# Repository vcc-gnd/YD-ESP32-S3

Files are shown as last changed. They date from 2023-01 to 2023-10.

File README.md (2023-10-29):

# YD-ESP32-S3 Core Board 

###### 简介：

YD-ESP32-S3核心板由源地工作室（VCC-GND Studio）设计，有需要可以浏览www.vcc-gnd.com 获取购买。该设备使用ESP32-S3芯片，可以用于物联网应用的测试原型机也就可以用于实际应用，配有两个usb一个是硬件的usb转串口(CH343P WCH 沁恒)，一个是ESP32-S3的usb口。

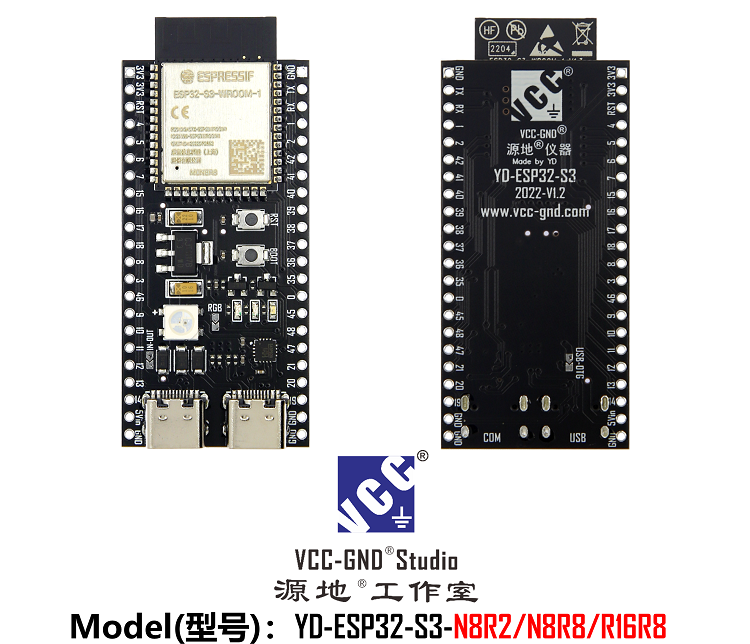
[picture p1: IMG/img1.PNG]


本指南将帮助您快速上手 YD-ESP32-S3，并提供该款开发板的详细信息。

YD-ESP32-S3 是一款入门级开发板，搭载 Wi-Fi + Bluetooth® LE 模组 ESP32-S3-WROOM-1。

板上模组的大部分管脚均已引出至开发板两侧排针，开发人员可根据实际需求，轻松通过跳线连接多种外围设备，也可将开发板插在面包板上使用。
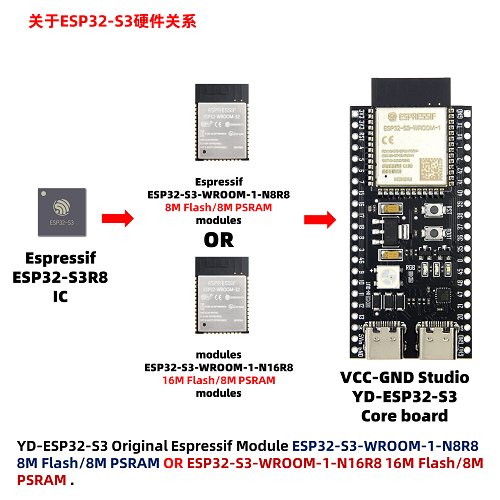
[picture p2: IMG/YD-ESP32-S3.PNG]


1、这就是一个ESP32-S3的最小核心板，使用时乐鑫公司的ESP32-S3模块。
2、无线功能专用的LDO电路，不用担心电流（功率）不够用的情况。
3、配有一颗WS2812-RGB LED(注意并不是通过GPIO直接点亮)。
4、RST按键用于外部复位功能，boot按键（配合rst按键可以引导进入bootloard 模式，在复位后可以当做用户按键，就是GPIO0）。
5、你会发现板子有两个TYPE-C接口（一个是直连usb（GPIO19 GPIO20）,另一个是USB转串口的usb口），配有硬件的usb转串口芯片（CH343）。

###### 硬件介绍：

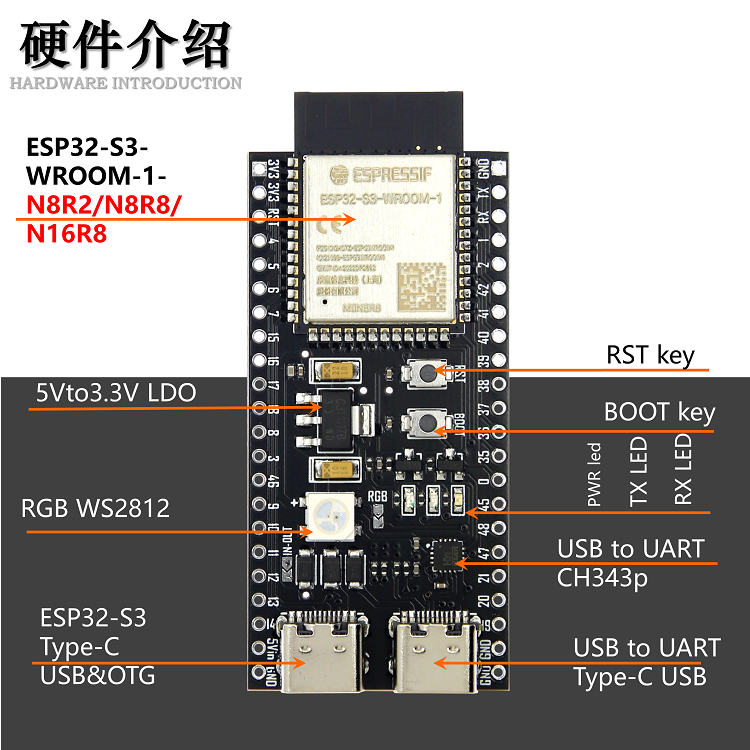
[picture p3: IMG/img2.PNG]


| 主要组件 | 介绍 |
| :--- | --- |
| ESP32-S3-WROOM-1 | ESP32-S3-WROOM-1 是通用型 Wi-Fi + 低功耗蓝牙 MCU 模组，具有丰富的外设接口、强大的神经网络运算能力和信号处理能力，专为人工智能和 AIoT 市场打造。ESP32-S3-WROOM-1  采用 PCB 板载天线。 |
| 5 V to 3.3 V LDO（5 V 转 3.3 V LDO） | 电源转换器，输入 5 V，输出 3.3 V,电流为1A |
| Pin Headers（排针） | 所有可用 GPIO 管脚（除 flash 的 SPI 总线）均已引出至开发板的排针。 |
| USB-to-UART Port（USB 转 UART 接口） | Type-c-USB 接口，可用作开发板的供电接口，可烧录固件至芯片，也可作为通信接口，通过板载 USB 转 UART 桥接器与芯片通信。 |
| Boot Button（Boot 键） | 下载按键。按住 **Boot** 键的同时按一下 **Reset** 键进入“固件下载”模式，通过串口下载固件。如果启动完毕可以当做普通的输入按键使用，使用到的IO为GPIO0。 |
| Reset Button（Reset 键） | 复位按键。 |
| USB Port（USB 接口） | ESP32-S3 USB OTG 接口，支持全速 USB 1.1 标准。ESP32-S3 USB 接口可用作开发板的供电接口，可烧录固件至芯片，可通过 USB 协议与芯片通信，也可用于 JTAG 调试。 |
| USB-to-UART Bridge（USB 转 UART 桥接器） | 芯片为CH343P,厂商为沁恒，网址为http://www.wch-ic.com/ 驱动：http://www.wch-ic.com/products/CH343.html? |
| RGB LED | 可寻址 RGB 发光二极管，由 GPIO48 驱动。型号为WS2812。 |
| PWR LED | 电源指示灯，板子供电后，亮起，不可以程序控制。 |
| TX LED | ESP32-S3的串口TXD线路上的led,当有串口数据发出时，LED闪烁，如果不使用串口功能可以当做GPIO使用,GPIO43 |
| RX LED | ESP32-S3的串口RXD线路上的led,当有串口数据接收时，LED闪烁，如果不使用串口功能可以当做GPIO使用，GPIO44 |

###### 备注:

在板载 ESP32-S3-WROOM-1 模组系列（使用 8 线 SPI flash/PSRAM）的开发板，管脚 GPIO35、GPIO36 和 GPIO37 已用于内部 ESP32-S3 芯片与 SPI flash/PSRAM 之间的通信，外部不可使用。

###### 开始开发应用:
通电前，请确保开发板完好无损。

###### 功能框图：
YD-ESP32-S3 的主要组件和连接方式如下图所示：

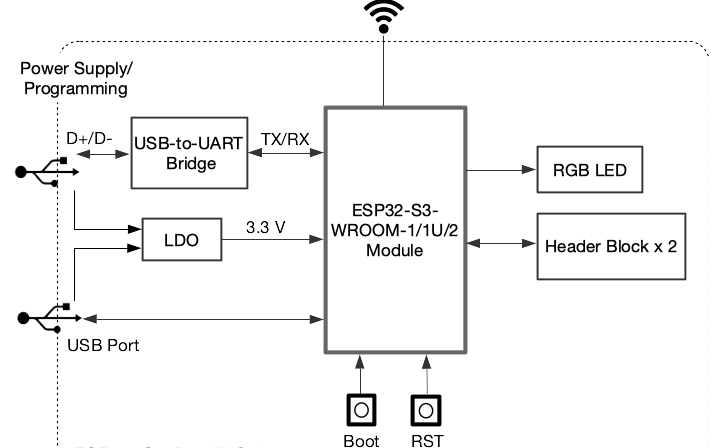
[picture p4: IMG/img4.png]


###### 电源选项:
您可从以下三种供电方式中任选其一给开发板供电：

USB 转 UART 接口供电或 ESP32-S3 USB 接口供电（选择其一或同时供电），默认供电方式（推荐）

5V 和 G (GND) 排针供电

3V3 和 G (GND) 排针供电

###### 排针:
下表列出了开发板两侧排针（P1 和 P2）的 名称 和 功能，排针的名称如图 YD-ESP32-S3正面 所示，排针的序号与 开发板原理图 (PDF) 一致。

###### P1

| 序号 | 名称 | 类型  | 功能 |
| ---- | ---- | ----- | --- |
| 1 | 3V3  | P | 3.3 V 电源 |
| 2 | 3V3  | P | 3.3 V 电源 |
| 3 | RST  | I | EN |
| 4 | 4 | I/O/T | RTC_GPIO4, GPIO4, TOUCH4, ADC1_CH3 |
| 5 | 5 | I/O/T | RTC_GPIO5, GPIO5, TOUCH5, ADC1_CH4 |
| 6 | 6 | I/O/T | RTC_GPIO6, GPIO6, TOUCH6, ADC1_CH5 |
| 7 | 7 | I/O/T | RTC_GPIO7, GPIO7, TOUCH7, ADC1_CH6 |
| 8 | 15 | I/O/T | RTC_GPIO15, GPIO15, U0RTS, ADC2_CH4, XTAL_32K_P |
| 9 | 16 | I/O/T | RTC_GPIO16, GPIO16, U0CTS, ADC2_CH5, XTAL_32K_N |
| 10 | 17 | I/O/T | RTC_GPIO17, GPIO17, U1TXD, ADC2_CH6 |
| 11 | 18 | I/O/T | RTC_GPIO18, GPIO18, U1RXD, ADC2_CH7, CLK_OUT3 |
| 12 | 8 | I/O/T | RTC_GPIO8, GPIO8, TOUCH8, ADC1_CH7, SUBSPICS1 |
| 13 | 3 | I/O/T | RTC_GPIO3, GPIO3, TOUCH3, ADC1_CH2 |
| 14 | 46 | I/O/T | GPIO46 |
| 15 | 9 | I/O/T | RTC_GPIO9, GPIO9, TOUCH9, ADC1_CH8, FSPIHD, SUBSPIHD |
| 16 | 10 | I/O/T | RTC_GPIO10, GPIO10, TOUCH10, ADC1_CH9, FSPICS0, FSPIIO4, SUBSPICS0 |
| 17 | 11 | I/O/T | RTC_GPIO11, GPIO11, TOUCH11, ADC2_CH0, FSPID, FSPIIO5, SUBSPID |
| 18 | 12 | I/O/T | RTC_GPIO12, GPIO12, TOUCH12, ADC2_CH1, FSPICLK, FSPIIO6, SUBSPICLK |
| 19 | 13 | I/O/T | RTC_GPIO13, GPIO13, TOUCH13, ADC2_CH2, FSPIQ, FSPIIO7, SUBSPIQ |
| 20 | 14 | I/O/T | RTC_GPIO14, GPIO14, TOUCH14, ADC2_CH3, FSPIWP, FSPIDQS, SUBSPIWP |
| 21 | 5V | P | 5 V 电源 |
| 22 | G | G | 接地 |

###### P2

| 序号 | 名称 | 类型  | 功能 |
| ---- | ---- | ----- | --- |
| 1 | G | G | 接地 |
| 2 | TX | I/O/T | U0TXD, GPIO43, CLK_OUT1 |
| 3 | RX | I/O/T | U0RXD, GPIO44, CLK_OUT2 |
| 4 | 1 | I/O/T | RTC_GPIO1, GPIO1, TOUCH1, ADC1_CH0 |
| 5 | 2 | I/O/T | RTC_GPIO2, GPIO2, TOUCH2, ADC1_CH1 |
| 6 | 42 | I/O/T | MTMS, GPIO42 |
| 7 | 41 | I/O/T | MTDI, GPIO41, CLK_OUT1 |
| 8 | 40 | I/O/T | MTDO, GPIO40, CLK_OUT2 |
| 9 | 39 | I/O/T | MTCK, GPIO39, CLK_OUT3, SUBSPICS1 |
| 10 | 38 | I/O/T | GPIO38, FSPIWP, SUBSPIWP |
| 11 | 37 | I/O/T | SPIDQS, GPIO37, FSPIQ, SUBSPIQ |
| 12 | 36 | I/O/T | SPIIO7, GPIO36, FSPICLK, SUBSPICLK |
| 13 | 35 | I/O/T | SPIIO6, GPIO35, FSPID, SUBSPID |
| 14 | 0 | I/O/T | RTC_GPIO0, GPIO0 |
| 15 | 45 | I/O/T | GPIO45 |
| 16 | 48 | I/O/T | GPIO48, SPICLK_N, SUBSPICLK_N_DIFF, RGB LED |
| 17 | 47 | I/O/T | GPIO47, SPICLK_P, SUBSPICLK_P_DIFF |
| 18 | 21 | I/O/T | RTC_GPIO21, GPIO21 |
| 19 | 20 | I/O/T | RTC_GPIO20, GPIO20, U1CTS, ADC2_CH9, CLK_OUT1, USB_D+ |
| 20 | 19 | I/O/T | RTC_GPIO19, GPIO19, U1RTS, ADC2_CH8, CLK_OUT2, USB_D- |
| 21 | G | G | 接地 |
| 22 | G | G | 接地 |

P：电源；I：输入；O：输出；T：可设置为高阻。

###### 引脚图：

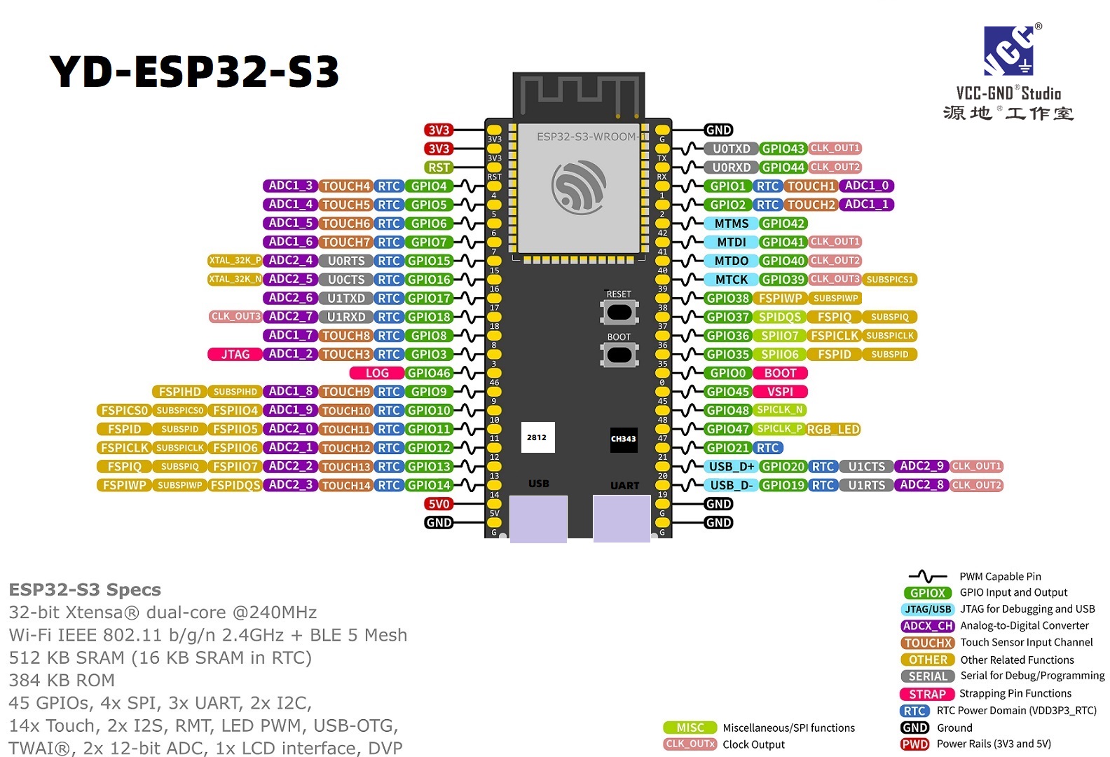
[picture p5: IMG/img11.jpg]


###### CH340芯片的驱动官方链接：

http://www.wch-ic.com/products/CH340.html?        ENGLISH

https://www.wch.cn/products/CH340.html?from=list     中文

Micropython固件下载：

ESP32-S3的下载擦除工具软件flash_download_tool_3.9.2_0在win下downloard tool。
注意：无需安装解压既用，双击小齿轮标志，选择ESP32-S3，develop，USART，剩下看图片，注意起始地址为0x00，前面打对号。如果不能下载可能是USB转串口驱动没有安好，先处理好驱动问题再来下载。

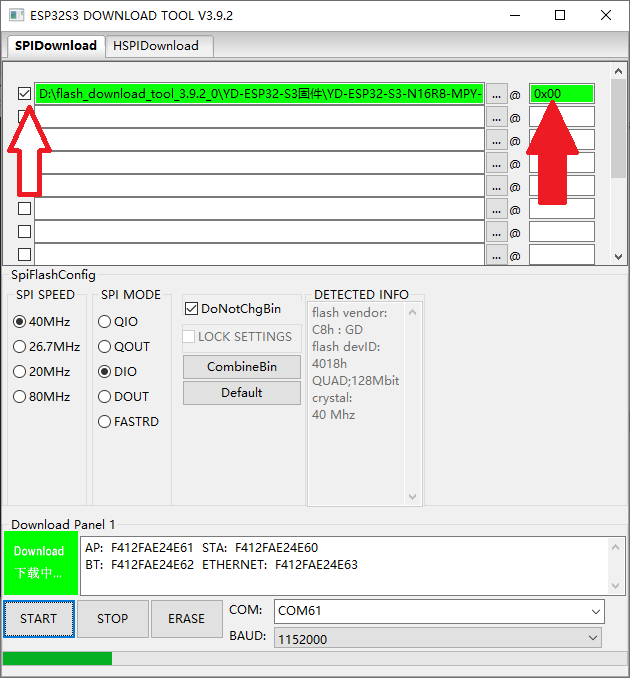
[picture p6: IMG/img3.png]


注意：

不能用thonny自带的所谓的ESP32下载器给ESP32-S3下载micropython固件(thonny自带的是给esp32下载的，型号并不是esp32-s3  地址也并不是S3的0x00而是ESP32的0x1000)，也不能使用micropython官方下载的带SPRAM固件，下载后也不能正常使用，正确的下载方式是使用乐鑫官方的flash tool下载工具，选择ESP32-S3 串口下载（USART）插入板子的COM端口的usb，选择对应的固件（我们源地自己改编的固件）起始地址是0x00 固件选择前打对号，最好先擦除再下载。
固件是1-开头链接的和固件下载软件是2-开头的链接，注意使用前最好更新一下CH343usb转串口的硬件驱动，注意事项在0-开头的资料链接中，在设备管理器中确认出现有……CH343字样COM才行。

如果下载TASMOTA固件，TASMOTA官方有自己的web下载。

https://tasmota.github.io/docs/

如果你下载自己的固件文件可以使用乐鑫的下载工具。

https://www.espressif.com.cn/en/home

这段文字是ESP32-S3的资料。 基础资料包括（硬件串口CH343驱动，源地版本micropython固件，下载固件的软件、micropython的IDE、原理图尺寸图等）：http://124.222.62.86/yd-data/YD-ESP32-S3/ 

如果计划使用官方的idf-C语言编程详细资料链接（例程就是的API参考）： https://docs.espressif.com/projects/esp-idf/zh_CN/latest/esp32s3/get-started/index.html 

如果计划使用Ardiuno编程资料链接： https://docs.espressif.com/projects/arduino-esp32/en/latest/getting_started.html#about-arduino-esp32 

如果计划使用micropython语言编程资料链接如下（注意快速入门看ESP32就行）： https://docs.micropython.org/en/latest/esp32/quickref.html
###### 山寨/假冒/劣质仿造的问题：

寨/假冒/劣质仿造我们源地（YD）开发板有很多，以深圳华强北最为猖獗，山寨者惯用的形式为直接打磨我们的开发板进行拍照抄板，以致山寨的产品隐患重重。现总结购买山寨板的危害（隐患）。
以YD-ESP32（ESP32/S2/S3/C3）系列为例：

1、山寨厂家为进一步追求利润，往往使用翻新，非官方器件，任意替换为同封装的廉价型号，乱选型，图利润

2、2812灯不焊接信号，无法使用2812，从侧面印证抄袭者不检查板子，图省事，压成本

3、山寨板出厂不检查（压缩成本），下完生产线就包装，发给消费者，省环节，图利润

4、山寨板由于照片抄袭，多处丝印抄错，容易误导消费者，抄袭者自己都搞不明白

5、山寨板抄袭是1.2版本是2022年早期版本，正版是1.4版本，山寨无法使用更新的功能，图省事不改进

6、山寨板使用的是第三方“山寨”模组（成本低），山寨模组没有经过阻抗匹配，在使用WIFI 蓝牙时候，功耗高信号差、易死机

7、山寨板由于在市面上找不到我们用专用LDO，就任意选择不合适型号，例如1117（成本低），压差大，易死机，信号差

8、山寨板使用高压差的二极管（大于0.7V管压降，成本低），造成后端LDO压差不足，进一步造成功耗高，易死机，信号差

9、山寨板不提供基本技术，就连资料都是直接复制我们的（资料还是我们早期的，最新资料山寨者都懒得找），钱收后，就不管了

10、山寨板启动有时候有问题，直接进入BootLoader，造成无法使用，山寨者都不明白这是什么问题！

11、山寨板仿冒者由于是照片抄板，所以没有原理图，让用户搞不懂如何使用，山寨者也不懂，造成产品难以使用。

有山寨者直接在山寨板子上印有YD-ESP32等字样以此来混淆视听，更有甚者，将我们官方网址WWW.VCC-GND.COM印在山寨仿冒品上，该行为已经触发相关法律，我们定会追究，请广大消费者不要贪图几毛钱~几块的一时便宜而承担以上种种风险，白白浪费时间和精力，支持源地支持正品，购买请认准源地，VCC-GND商标。

###### 通过内部交换矩阵可以实现引脚上的任意功能：

在各种ESP32系列文档介绍中注明了具备各种外设通讯功能例如I2C、I2S、UART、SPI等。但是又在功能引脚上示意图没有标注这些功能是哪个引脚。这个疑问在外设管脚分配中得到了解答，诸如I2C、I2S、UART、SPI等外设接口可以被定义为任意GPIO管脚，所以就没有必要在 功能示意图上标注出来了，反正任何一个GPIO都可以赋予这些外设接口I2C、I2S、UART、SPI功能所需要的引脚某个引脚功能。

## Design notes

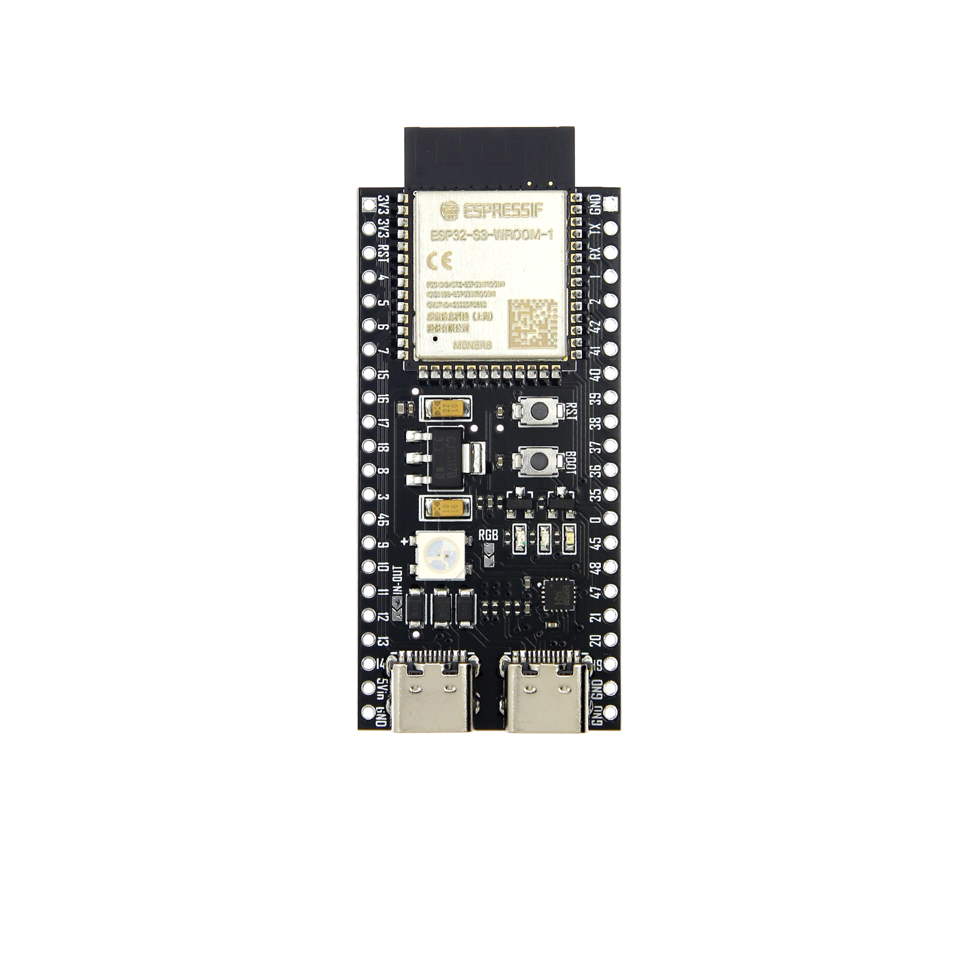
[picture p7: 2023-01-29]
5-public-YD-ESP32-S3-Hardware info/YD-ESP32-S3.PNG

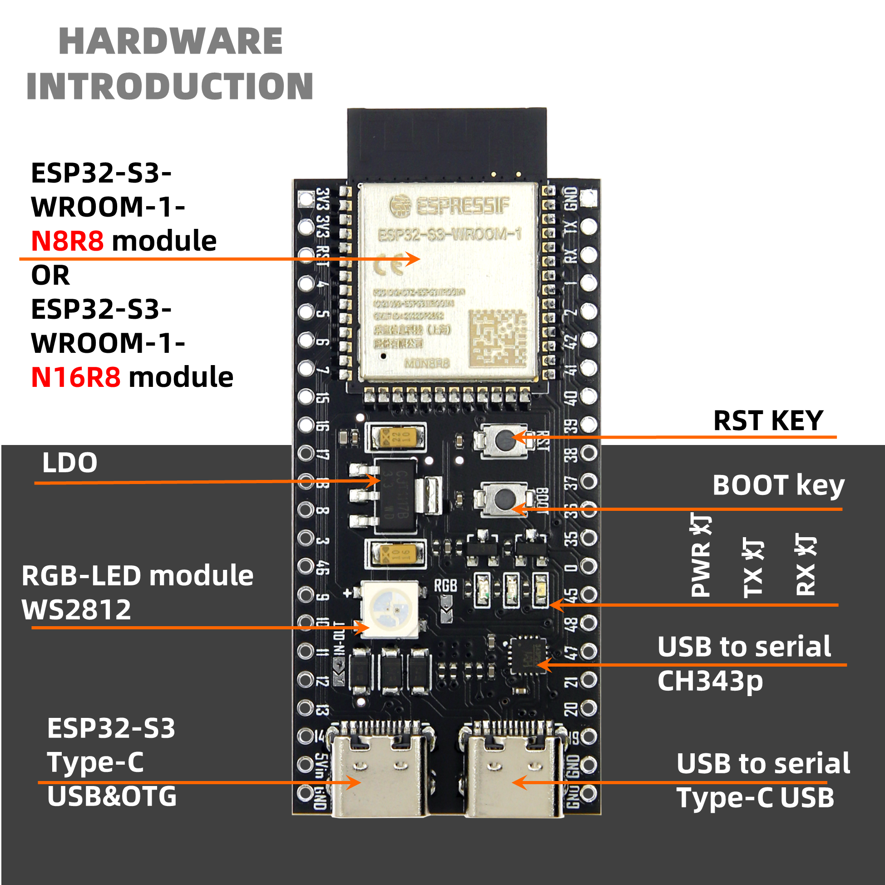
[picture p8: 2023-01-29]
5-public-YD-ESP32-S3-Hardware info/S3-V1.2 (14).PNG

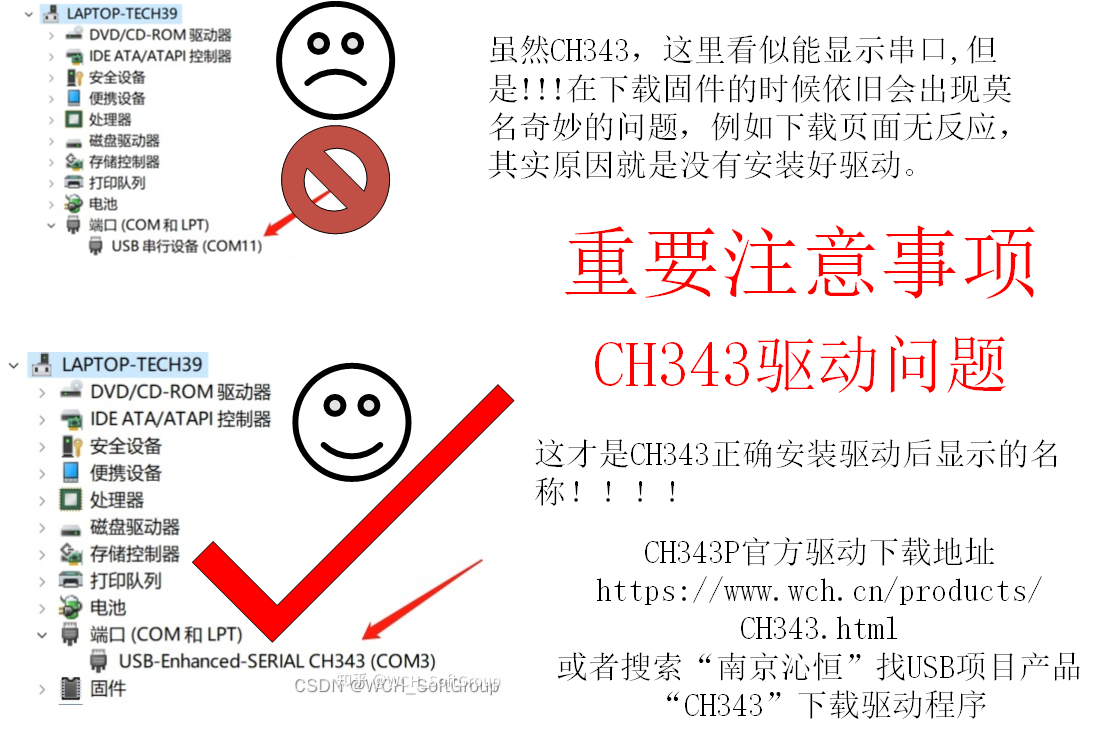
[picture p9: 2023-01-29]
0-public-USB to serial CH343 driver(important)/0-CH343驱动说明.png

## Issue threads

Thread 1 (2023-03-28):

RGB LED on PIN 48 not working?

PBrunot, 2023-03-28:
I am unable to get the RGB LED to work on  YD-ESP32-S3 N8R2 2022-V1.3 with standard Micropython and recent Micropython with NeoPixel library. Oscilloscope attached to GPIO48 shows no 800 KHz output.

Another user has the same issue, with board V1.4.

Is this a known problem ? Any workaround ?

See for more details : https://github.com/orgs/micropython/discussions/11097

PBrunot, 2023-03-29:
I think I have a defective ESP32 because the GPIO 48 is not outputting any signal, and if I connect NeoPixel on board to GPIO 10, it works fine.

mikadoryu, 2023-03-30:
First of all, do I solder the rgb pads that connect it to pin 48? I had the same problem that the rgb led did not work until I had to activate the led.
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

tyg6, 2023-06-24:
@mikadoryu @PBrunot I had the same problem, could you please explain more simply how to activate the led? Many thanks!
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

PBrunot, 2023-06-24:
@tyg6  : you just need to add a bit of solder on the jumper below the RGB letters with your soldering pan, so that the circuit to the NeoPixel is closed. From your photo there is a gap between the two jumpers pins, so the NeoPixel will not work without this addition.

tyg6, 2023-06-24:
@PBrunot Thanks for your quick reply! Got your point!

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

tyg6, 2023-06-24:
It works! finally I found the gap should be a 0603 10kΩ resistor.
It's a good design, cause you can use the GPIO 48 for other functions.
But it is frustrating there is no document for this tip.

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

vcc-gnd, 2023-09-07:
你购买是板子是山寨板，需要短接

At 2023-06-25 03:28:19, "Shuhu Liu" ***@***.***> wrote:

It works! finally I found the gap should be a 0603 10kΩ resistor.
It's a good design, cause you can use the GPIO 48 for other functions.
But it is frustrating there is no document for this tip.

—
Reply to this email directly, view it on GitHub, or unsubscribe.
You are receiving this because you are subscribed to this thread.Message ID: ***@***.***>

Closed 2023-03-29.

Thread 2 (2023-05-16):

No autoreset

Adrianotiger, 2023-05-16:
After programming the ESP over the UART (right USB connector), the ESP should autoreset.
This is the output:
```
ESP-ROM:esp32s3-20210327
Build:Mar 27 2021
rst:0x1 (POWERON),boot:0x0 (DOWNLOAD(USB/UART0))
waiting for download
```
I need to press the RESET button to reset the module.

Same happens when I connect the USB to power the module. It doesn't start until I press the RESET button manually.

Adrianotiger, 2023-05-16:
Sorry. My fault. the text appears but the esp is booting correctly.

Closed 2023-05-16.

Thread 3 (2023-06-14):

Running esp-iot UVC camera project on this board

MrNash97, 2023-06-14:
I want to try the [UVC camera project ](https://github.com/espressif/esp-iot-solution/tree/master/examples/usb/host/usb_camera_mic_spk) from the esp-iot-solution GitHub page. I noticed a few things on the hardware description and assumed this board fell into category ii.
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
I try to give it a go and plug my UVC camera into the USB-OTG port, but the camera doesn't get powered on. I tried to check the output voltage from the USB-OTG but nothing.

Is there a way to make the USB-OTG port deliver 5V DC output?
I'm using V1.3, and here is the picture of my board.
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

mrnrone, 2024-11-24:
I am not sure what's the best solution here. I am just guessing but you might need to do a little more soldering.

https://forum.arduino.cc/t/chinese-esp32-s3-5v-pin-warning/1192758

Another thread about those soldering pads:

https://www.reddit.com/r/esp32/comments/10rdngp/thirdparty_esp32s3_development_boards_inout_and/?rdt=39953

I hope it helps.

Btw how should those soldering pads to be used?
What happens if I solder in-out or usb-otg? (Rgb is okay :))

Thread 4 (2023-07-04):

YD-EPS32-23 2022-V1.3 Development Board RGB LED Not working

amin-is, 2023-07-04:
Can you give an example code for this board RGB LED blinking OR NeoPixel example code

vcc-gnd, 2023-07-05:
You should have purchased pirated hardware, but I can provide you with technical support.

W2812 Micropython CODE：
from machine import Pin
from neopixel import NeoPixel
#ESP32-S3 48PIN ESP32-C3 8PIN ESP32 16PIN ESP32-S2 18PIN
pin = Pin(48, Pin.OUT)
np = NeoPixel(pin, 1)
np[0] = (10,0,0) #R B G max 255 255 255
np.write()
r, g, b = np[0]

At 2023-07-05 01:15:10, "Amin" ***@***.***> wrote:

Can you give an example code for this board RGB LED blinking OR NeoPixel example code

—
Reply to this email directly, view it on GitHub, or unsubscribe.
You are receiving this because you are subscribed to this thread.Message ID: ***@***.***>

amin-is, 2023-07-05:
Can you give me arduino c language example. I have purchase a board when backside printed was only Board model, version and your web address and no any others information like [this board ](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). May be this board is copy..

buxiua, 2023-07-24:
@amin-is Hey guy，I have the same problem but I have fixed it，your board may be a knockoff，please see #1 , and this is my program to blink RGB using arduino。
```C
#include <Arduino.h>
#include <FastLED.h>

#define LED_PIN 48
#define LED_NUMS 1

CRGB leds[LED_NUMS];

void setup() {
  Serial.begin(115200);
  FastLED.addLeds<NEOPIXEL, LED_PIN>(leds, LED_NUMS);
}

void loop() {
  leds[0] = CRGB(255, 0, 0);
  FastLED.show();
  Serial.print("RED \n");
  delay(1000);
  leds[0] = CRGB(0, 255, 0);
  FastLED.show();
  Serial.print("Green \n");
  delay(1000);
  leds[0] = CRGB(0, 0, 255);
  FastLED.show();
  Serial.print("Blue \n");
  delay(1000);
}
```
of course it work correctly!

vcc-gnd, 2023-09-07:
你购买的板子可能为山寨板子，注意通信线路是否连接

At 2023-07-24 15:45:36, "buxiua" ***@***.***> wrote:

@amin-is Hey guy，I have the same problem but I have fixed it，your board may be a knockoff，please see #1 , and this is my program to blink RGB using arduino。

#include<Arduino.h>#include<FastLED.h>#defineLED_PIN 48
#defineLED_NUMS 1

CRGBleds[LED_NUMS];

voidsetup() {
  Serial.begin(115200);
  FastLED.addLeds<NEOPIXEL, LED_PIN>(leds, LED_NUMS);
}

voidloop() {
  leds[0] =CRGB(255, 0, 0);
  FastLED.show();
  Serial.print("RED \n");
  delay(1000);
  leds[0] =CRGB(0, 255, 0);
  FastLED.show();
  Serial.print("Green \n");
  delay(1000);
  leds[0] =CRGB(0, 0, 255);
  FastLED.show();
  Serial.print("Blue \n");
  delay(1000);
}

of course it work correctly!

—
Reply to this email directly, view it on GitHub, or unsubscribe.
You are receiving this because you commented.Message ID: ***@***.***>

dzalf, 2023-11-16:
For newcomers and those having issues with the onboard NEOPIXEL, this is the code from the response above  (by @vcc-gnd ) using code tags so that you can easily copy-paste in your sketch. Remember to plug in your USB-C cable in the port on the right-hand side.

Thanks, guys from @vcc-gnd for making this fantastic version of the ESP32-S3. It is a powerhouse!

``` cpp
/**
   @file: ESP32-S3_DevModule_RGB_test.ino Board from http://vcc-gnd.com
   @brief: Basic onboard WS2012 - NEOPIXEL test
            Driving pin: 48
   @deps: <FastLED> library: https://github.com/FastLED/FastLED

*/

#include <Arduino.h>
#include <FastLED.h>

#define LED_PIN 48
#define LED_NUMS 1

CRGB leds[LED_NUMS];

void setup() {

  Serial.begin(115200);
  FastLED.addLeds<NEOPIXEL, LED_PIN>(leds, LED_NUMS);
}

void loop() {

  leds[0] = CRGB(255, 0, 0);
  FastLED.show();

  Serial.print("RED \n");

  delay(1000);

  leds[0] = CRGB(0, 255, 0);
  FastLED.show();

  Serial.print("Green \n");

  delay(1000);

  leds[0] = CRGB(0, 0, 255);
  FastLED.show();

  Serial.print("Blue \n");

  delay(1000);

}

```

TechRelief, 2023-12-22:
F.Y.I. This board has a solder jumper marked RGB right next to the RBG LED which you have to short with a blob of solder and then the standard RGB Arduino sample code will work.  The RGB led is connected to GPIO pin 38 and I guess the jumper is there in case you want to use this pin for a different purpose.

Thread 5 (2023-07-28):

Please provide Altium-Designer Project

DerPicknicker, 2023-07-28:
Hello,

I bought your Board and it works fine for me. I want to Add some Components on the Back. Is there a possibility that you can publish the schematics from Altium? So that I don't need to re-draw and make mistakes and I can just start from a working Board?

Would be great and thank you in advance!

DerPicknicker, 2023-07-31:
@vcc-gnd any plans to publish the schematics?

DerPicknicker, 2024-06-18:
@robertlipe .. It's resolved. I don't want to redraw the whole board. If it's already available.

qwqawawow, 2024-12-05:
PCB is not open-source.They sell the board.This repo is only used for document

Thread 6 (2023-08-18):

您好，我是一名iOS开发者，我开发的功能很简单，蓝牙传输文件

xianengqi, 2023-08-18:
遇到的问题是，文件大小只有300kb,使用蓝牙传输到此IOT设备时，传输速度只有7kb/s ,MTU值我设置的是500字节,优化了好几天了传输速率始终上不来。
这是我的完整代码
```SwiftUI
import CoreBluetooth
import SwiftUI

struct ContentView: View {
  @State private var fileURL: URL? = nil
  @State private var status: String = "Not Connected"
  @StateObject private var bluetoothManager = BluetoothManager()

  var transferRateText: String {
    let transferRateKB = bluetoothManager.transferRate / 1024
    if transferRateKB < 1024 {
      return String(format: "%.2f KB/s", transferRateKB)
    } else {
      let transferRateMB = transferRateKB / 1024
      return String(format: "%.2f MB/s", transferRateMB)
    }
  }

  var body: some View {
    VStack {
      Button("Select File") {
        // TODO: Select file
        selectFile()
      }
      .padding()

      Text("Status: \(bluetoothManager.status)")
        .padding()
      Text("Transfer Rate: \(transferRateText)")
        .padding()

      Text("Total Time: \(bluetoothManager.totalTime, specifier: "%.2f") seconds")
        .padding()
      List(bluetoothManager.discoveredDevices, id: \.identifier) { device in
        HStack {
          Text(device.name ?? "Unknown")
          Spacer()
          Button("Connect") {
            bluetoothManager.connectToDevice(device)
          }
        }
      }
    }
  }

  private func selectFile() {
    bluetoothManager.presentFilePicker()
  }
}

#Preview {
  ContentView()
}

class BluetoothManager: NSObject, ObservableObject, CBCentralManagerDelegate, CBPeripheralDelegate {
  private var centralManager: CBCentralManager!
  private var peripheral: CBPeripheral?
  public var fileTransferCharacteristic: CBCharacteristic?
  @Published var status: String = "Not Connected"
  @Published var discoveredDevices: [CBPeripheral] = []
  private var startTime: Date?
  private var endTime: Date?
  var fileData: Data!
  @Published var transferRate: Double = 0.0
  @Published var totalTime: Double = 0.0
  private var connectionParameters: [String: Any]?

  override init() {
    super.init()
    centralManager = CBCentralManager(delegate: self, queue: nil)
  }

  func centralManagerDidUpdateState(_ central: CBCentralManager) {
    if central.state == .poweredOn {
      centralManager.scanForPeripherals(withServices: nil, options: nil)
    }
  }

  // TODO: Implement other delegate methods

  func centralManager(_ central: CBCentralManager, didDiscover peripheral: CBPeripheral, advertisementData: [String: Any], rssi RSSI: NSNumber) {
    if !discoveredDevices.contains(where: { $0.identifier == peripheral.identifier }) {
      discoveredDevices.append(peripheral)
    }
  }

  func centralManager(_ central: CBCentralManager, didConnect peripheral: CBPeripheral) {
    print("Connected to peripheral: \(peripheral.name ?? "Unknown")")
    status = "Connected to \(peripheral.name ?? "Unknown")"
    peripheral.delegate = self
    peripheral.discoverServices(nil)
  }

  func peripheral(_ peripheral: CBPeripheral, didDiscoverServices error: Error?) {
    if let error = error {
      print("Error discovering services: \(error)")
      return
    }

    for service in peripheral.services ?? [] {
      print("Discovered service: \(service.uuid)")
      peripheral.discoverCharacteristics(nil, for: service)
    }
  }

  func peripheral(_ peripheral: CBPeripheral, didDiscoverCharacteristicsFor service: CBService, error: Error?) {
    if let error = error {
      print("Error discovering characteristics: \(error)")
      return
    }

    for characteristic in service.characteristics ?? [] {
      print("Discovered characteristic: \(characteristic.uuid)")
      if characteristic.uuid == CBUUID(string: "0000ff01-0000-1000-8000-00805f9b34fb") { // Replace with your characteristic UUID
        fileTransferCharacteristic = characteristic
        // Check MTU size
        let mtu = peripheral.maximumWriteValueLength(for: .withResponse)
        print("MTU size: \(mtu) bytes")
      }
    }
  }

  public func sendFileData(_ data: Data, to characteristic: CBCharacteristic?) {
    guard let characteristic = characteristic else { return }
//    let mtu = 500
    let mtu = peripheral!.maximumWriteValueLength(for: .withResponse)
    var offset = 0

    DispatchQueue.global(qos: .background).async { // Move to a background thread
      self.startTime = Date() // Record the start time

      let writeType: CBCharacteristicWriteType = characteristic.properties.contains(.writeWithoutResponse) ? .withoutResponse : .withResponse

      while offset < data.count {
        let chunkSize = min(mtu, data.count - offset)
        let chunk = data.subdata(in: offset ..< offset + chunkSize)
        self.peripheral?.writeValue(chunk, for: characteristic, type: writeType)
        offset += chunkSize
      }
    }
  }

  func peripheral(_ peripheral: CBPeripheral, didWriteValueFor characteristic: CBCharacteristic, error: Error?) {
    if let error = error {
      print("Error writing value: \(error)")
      status = "Error: \(error)"
      return
    }

    print("Successfully wrote value for characteristic: \(characteristic.uuid)")

    endTime = Date() // Record the end time

    if let startTime = startTime, let endTime = endTime {
      let elapsedTime = endTime.timeIntervalSince(startTime)
      let fileSize = Double(fileData.count)
      let transferRateValue = fileSize / elapsedTime // bytes per second

      print("File transferred successfully")
      print("Transfer Rate: \(transferRateValue) B/s")
      print("Total Time: \(elapsedTime) seconds")

      // Update the published variables
      transferRate = transferRateValue
      totalTime = elapsedTime
    }
  }

  func presentFilePicker() {
    let filePicker = UIDocumentPickerViewController(documentTypes: ["public.data"], in: .import)
    filePicker.delegate = self
    UIApplication.shared.windows.first?.rootViewController?.present(filePicker, animated: true, completion: nil)
  }

  func connectToDevice(_ device: CBPeripheral) {
    peripheral = device
    peripheral?.delegate = self
    centralManager.connect(peripheral!, options: nil)
  }
}

extension BluetoothManager: UIDocumentPickerDelegate {
  func documentPicker(_ controller: UIDocumentPickerViewController, didPickDocumentsAt urls: [URL]) {
    guard let url = urls.first else { return }

    // Create a temporary directory for the file
    let tempURL = FileManager.default.temporaryDirectory.appendingPathComponent(url.lastPathComponent)

    do {
      // Check if file exists at temporary directory
      if FileManager.default.fileExists(atPath: tempURL.path) {
        // Remove the file if it exists
        try FileManager.default.removeItem(at: tempURL)
      }

      // Copy the file to the temporary directory
      try FileManager.default.copyItem(at: url, to: tempURL)

      // Read the file data
//      let fileData = try Data(contentsOf: tempURL)
      fileData = try Data(contentsOf: tempURL)

      // Send the file data
      sendFileData(fileData, to: fileTransferCharacteristic)
    } catch {
      print("Error reading file data: \(error)")
      status = "Error: \(error.localizedDescription)"
    }
  }
}

 ```

xianengqi, 2023-08-18:
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

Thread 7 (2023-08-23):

firmware for N16R8?

pumarada, 2023-08-23:
Hello,

I have a N16R8 type board and I don't see that you have firmware for it. Would it be possible for you to create it, please?

Best regards!!!

ouening, 2023-09-01:
同样的问题，在https://circuitpython.org/board/yd_esp32_s3_n16r8/下载的固件无法使用

guavuavcycayfayqvqu, 2024-07-04:
> 同样的问题，在[https://circuitpython.org/board/yd_esp32_s3_n16r8/下载的固件无法使用](https://circuitpython.org/board/yd_esp32_s3_n16r8/%E4%B8%8B%E8%BD%BD%E7%9A%84%E5%9B%BA%E4%BB%B6%E6%97%A0%E6%B3%95%E4%BD%BF%E7%94%A8)

But how to flash? Esp flash tool gui/cmd not working 😂

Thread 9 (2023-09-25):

Provided firmware MP 1.19.1 machine.TouchPad class missing.

palillo0, 2023-09-25:
Hi, the YD-ESP32-S3 N8R8 and N8R2 Micropython firmware 1.1.19 does not support the TouchPad class on the machine module.  It is just missing.
I am trying to compile MP 1.19.1 from source but I am not able to compile it.  On the boards section there is no vcc-gnd or YD-esp32-s3 parameters files to compile.
Can yo provide instructions for compiling and or update firmware with TouchPad support ?
I am trying to build with ESP-IDF 4.4 but I am not able to compile it, only ESP-IDF 4.2.2 is working for me but it does not have esp32-s3 support.
Thanks.

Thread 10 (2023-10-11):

ESP32-S3 Wroom programming not working

Keksi71, 2023-10-11:

Closed 2023-10-11.

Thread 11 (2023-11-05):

5V供电问题

zhangxiaokai007, 2023-11-05:
您好，我注意到P1的21管脚为5V电源，想问一下这个管脚可以通过短接IN-OUT来实现5V输出吗？

vcc-gnd, 2023-11-05:
可以

---- 回复的原邮件 ----
| 发件人 | ***@***.***> |
| 日期 | 2023年11月05日 12:24 |
| 收件人 | ***@***.***> |
| 抄送至 | ***@***.***> |
| 主题 | [vcc-gnd/YD-ESP32-S3] 5V供电问题 (Issue #11) |

您好，我注意到P1的21管脚为5V电源，想问一下这个管脚可以通过短接IN-OUT来实现5V输出吗？

—
Reply to this email directly, view it on GitHub, or unsubscribe.
You are receiving this because you are subscribed to this thread.Message ID: ***@***.***>

Closed 2023-11-13.

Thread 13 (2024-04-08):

Micropython下内置温度和霍尔传感器无法使用

anders0821, 2024-04-08:
刷了Micropython固件：YD-ESP32-S3-N16R8-MPY-V1.1.bin
内置温度和霍尔传感器无法使用，esp32模块存在，但没有函数hall_sensor()和raw_temperature()

>>> import esp32
>>> esp32.hall_sensor()
Traceback (most recent call last):
  File "<stdin>", line 2, in <module>
AttributeError: 'module' object has no attribute 'hall_sensor'
>>> esp32.raw_temperature()
Traceback (most recent call last):
  File "<stdin>", line 1, in <module>
AttributeError: 'module' object has no attribute 'raw_temperature'

genicsoft, 2024-06-08:
你应该去问Micropython 或者用最新版mpy固件

goldenfreemanchina, 2024-12-11:
`>>>import esp32
print(dir(esp32))
`

输出是这样的：
```
MPY: soft reboot
['__class__', '__name__', 'HEAP_DATA', 'HEAP_EXEC', 'NVS', 'Partition', 'RMT', 'ULP', 'WAKEUP_ALL_LOW', 'WAKEUP_ANY_HIGH', '__dict__', 'gpio_deep_sleep_hold', 'idf_heap_info', 'mcu_temperature', 'wake_on_ext0', 'wake_on_ext1', 'wake_on_touch', 'wake_on_ulp']
```

你要的是esp32.mcu_temperature()；

goldenfreemanchina, 2024-12-11:
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

```
>>>import esp32
print(dir(esp32))
```

输出是这样的：
```
MPY: soft reboot
['__class__', '__name__', 'HEAP_DATA', 'HEAP_EXEC', 'NVS', 'Partition', 'RMT', 'ULP', 'WAKEUP_ALL_LOW', 'WAKEUP_ANY_HIGH', '__dict__', 'gpio_deep_sleep_hold', 'idf_heap_info', 'mcu_temperature', 'wake_on_ext0', 'wake_on_ext1', 'wake_on_touch', 'wake_on_ulp']
```

你要的是esp32.mcu_temperature()；

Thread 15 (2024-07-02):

N8R2 PSRAM ID read error

Omirax, 2024-07-02:
Hello!

I have 2x N8R2. After flash YD-ESP32-S3-N8R2-MPY-V1.1.bin

```
[22:41:37]ESP-ROM:esp32s3-20210327
[22:41:37]Build:Mar 27 2021
[22:41:37]rst:0x1 (POWERON),boot:0x8 (SPI_FAST_FLASH_BOOT)
[22:41:37]SPIWP:0xee
[22:41:37]mode:DIO, clock div:1
[22:41:37]load:0x3fce3808,len:0xf24
[22:41:37]load:0x403c9700,len:0xc44
[22:41:37]load:0x403cc700,len:0x2d74
[22:41:37]entry 0x403c98f4
[22:41:37]E (243) psram: PSRAM ID read error: 0x00ffffff
[22:41:37]E (243) spiram: SPI RAM enabled but initialization failed. Bailing out.
[22:41:37]E (10) spiram: SPI RAM not initialized
[22:41:37]
[22:41:37]abort() was called at PC 0x42006940 on core 1
[22:41:37]
[22:41:37]
[22:41:37]Backtrace:0x40375c3e:0x3fce4b900x403824a5:0x3fce4bb0 0x403888d6:0x3fce4bd0 0x42006940:0x3fce4c40 0x42007157:0x3fce4c60
[22:41:37]
[22:41:37]
[22:41:37]
[22:41:37]
[22:41:37]ELF file SHA256: c7c606756726b3c0
[22:41:37]
[22:41:37]Rebooting..
```

After flash YD-ESP32-S3-N8R8-MPY-V1.1.bin I have

```
22:46:30.183 -> ESP-ROM:esp32s3-20210327
22:46:30.183 -> Build:Mar 27 2021
22:46:30.183 -> rst:0x1 (POWERON),boot:0x8 (SPI_FAST_FLASH_BOOT)
22:46:30.183 -> SPIWP:0xee
22:46:30.183 -> mode:DIO, clock div:1
22:46:30.183 -> load:0x3fce3808,len:0xf24
22:46:30.223 -> load:0x403c9700,len:0xc44
22:46:30.223 -> load:0x403cc700,len:0x2d74
22:46:30.223 -> entry 0x403c98f4
22:46:30.554 -> MicroPython v1.19.1 on 2022-09-23; YD-ESP32S3-N8R8 with ESP32S3R8
22:46:30.554 -> Type "help()" for more information
```

And I'm not sure if spram was initialized or not.
What am I doing wrong?

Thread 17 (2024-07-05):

this is original espressif modul?

rifatdanur, 2024-07-05:
is this guaranteed with the original chip module from espressif? if so I'll buy it, I'm looking for a board with the original module.

vcc-gnd, 2024-07-05:
是的，官方的模组

---- Replied Message ----
| From | ***@***.***> |
| Date | 07/05/2024 11:54 |
| To | ***@***.***> |
| Cc | ***@***.***> |
| Subject | [vcc-gnd/YD-ESP32-S3] this is original espressif modul? (Issue #17) |

is this guaranteed with the original chip module from espressif? if so I'll buy it, I'm looking for a board with the original module.

—
Reply to this email directly, view it on GitHub, or unsubscribe.
You are receiving this because you are subscribed to this thread.Message ID: ***@***.***>

rifatdanur, 2024-07-05:
好的，谢谢

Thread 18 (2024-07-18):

Is this board compatible with Arduino framework?

AlexC-0806, 2024-07-18:
Hello,

I recently purchased a board from Aliexpress and have been searching for relevant documentation. I noticed that the provided firmware on this GitHub page is exclusively for MicroPython.

My primary concern is whether this board is compatible with the Arduino framework and, more specifically, if it can be programmed via the PlatformIO IDE in Visual Studio Code. Are there any special configurations required to facilitate this?

Additionally, I believe this board should technically be identical to the one detailed here: https://docs.espressif.com/projects/esp-idf/en/latest/esp32s3/hw-reference/esp32s3/user-guide-devkitc-1.html. Given this, I assume there should be no issues programming it using Visual Studio Code and PlatformIO.

Could anyone confirm these assumptions or provide further guidance? I am particularly interested in understanding the exact compatibility of this board with the PlatformIO and Arduino framework.

Thank you in advance for your assistance.

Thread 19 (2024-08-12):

Connect to USB Keyboard

corianspirit, 2024-08-12:
Hi,
I want to connect the yd-esp32-s3 board to a USB keyboard via the USB-C port instead of the pin 19-20.
Do you have the library for it ? The connection USB-OTG near the port has to be connected for this purpose
I am using Arduino IDE (sketch)

Thank you,

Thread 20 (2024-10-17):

unable to get Serial1 working

misc-protolabs, 2024-10-17:
Serial0 (port on the R viewed from the top of the board) works as expected for:
- program
- read/write
using:
-   Serial0.begin( 115200, SERIAL_8N1, 44, 43);

Serial1 shows NO SIGNS OF LIFE for:
- read/write
using:
-   Serial1.begin( 115200, SERIAL_8N1, 20, 19);
-   Serial1.begin( 115200, SERIAL_8N1, 19, 20);

misc-protolabs, 2024-10-17:
NOTE: per https://github.com/vcc-gnd/YD-ESP32-S3/blob/main/IMG/img4.png

there is continuity between pins [20,19] and the pins on the USB port on the L (viewed from the top)

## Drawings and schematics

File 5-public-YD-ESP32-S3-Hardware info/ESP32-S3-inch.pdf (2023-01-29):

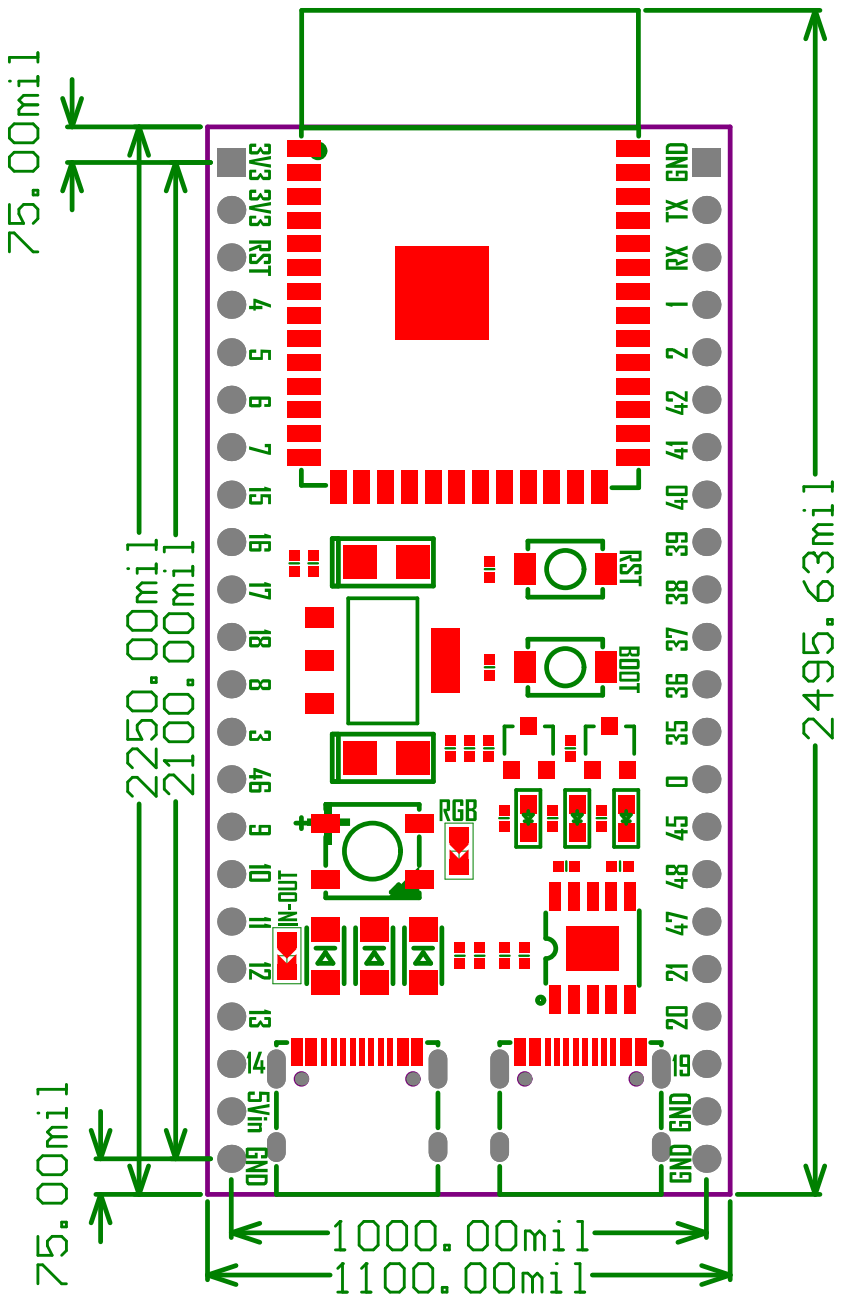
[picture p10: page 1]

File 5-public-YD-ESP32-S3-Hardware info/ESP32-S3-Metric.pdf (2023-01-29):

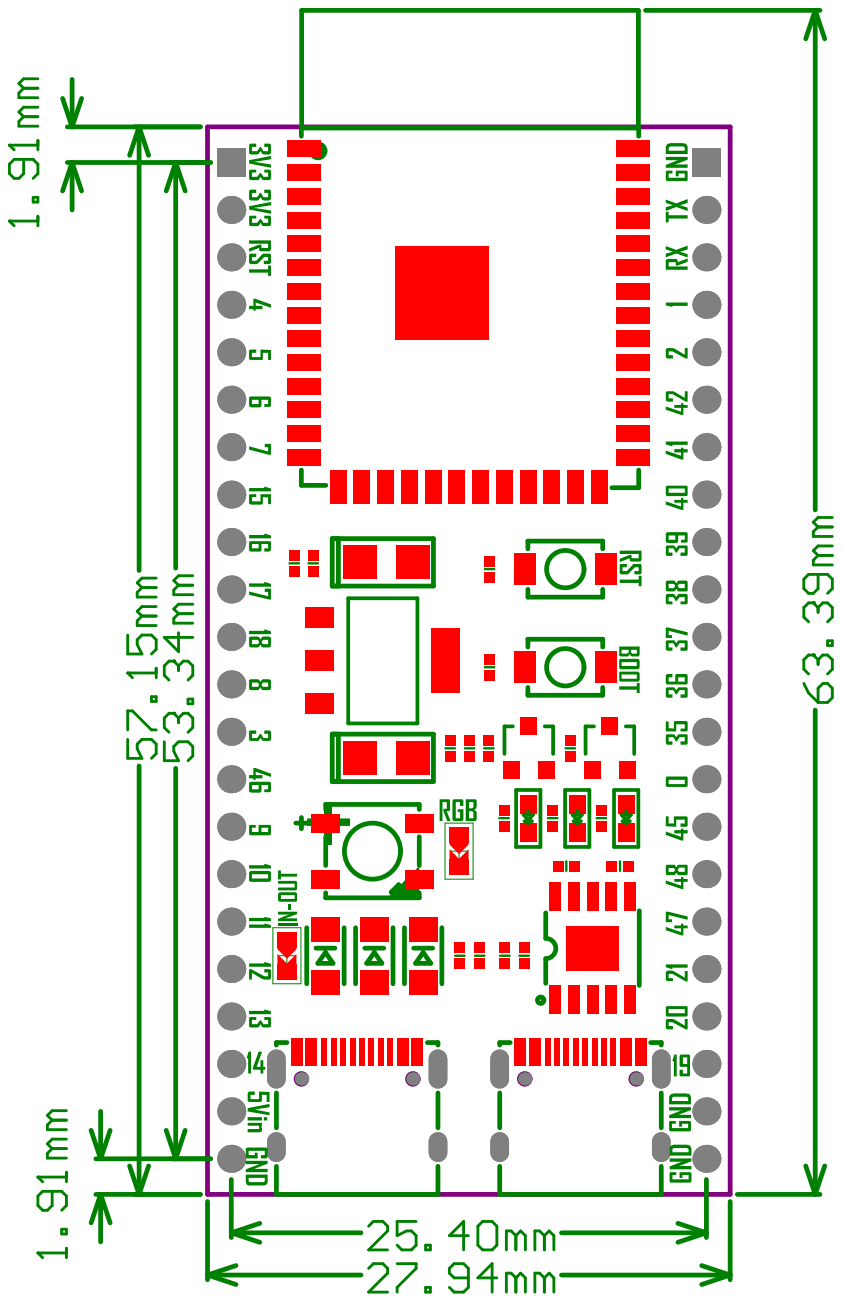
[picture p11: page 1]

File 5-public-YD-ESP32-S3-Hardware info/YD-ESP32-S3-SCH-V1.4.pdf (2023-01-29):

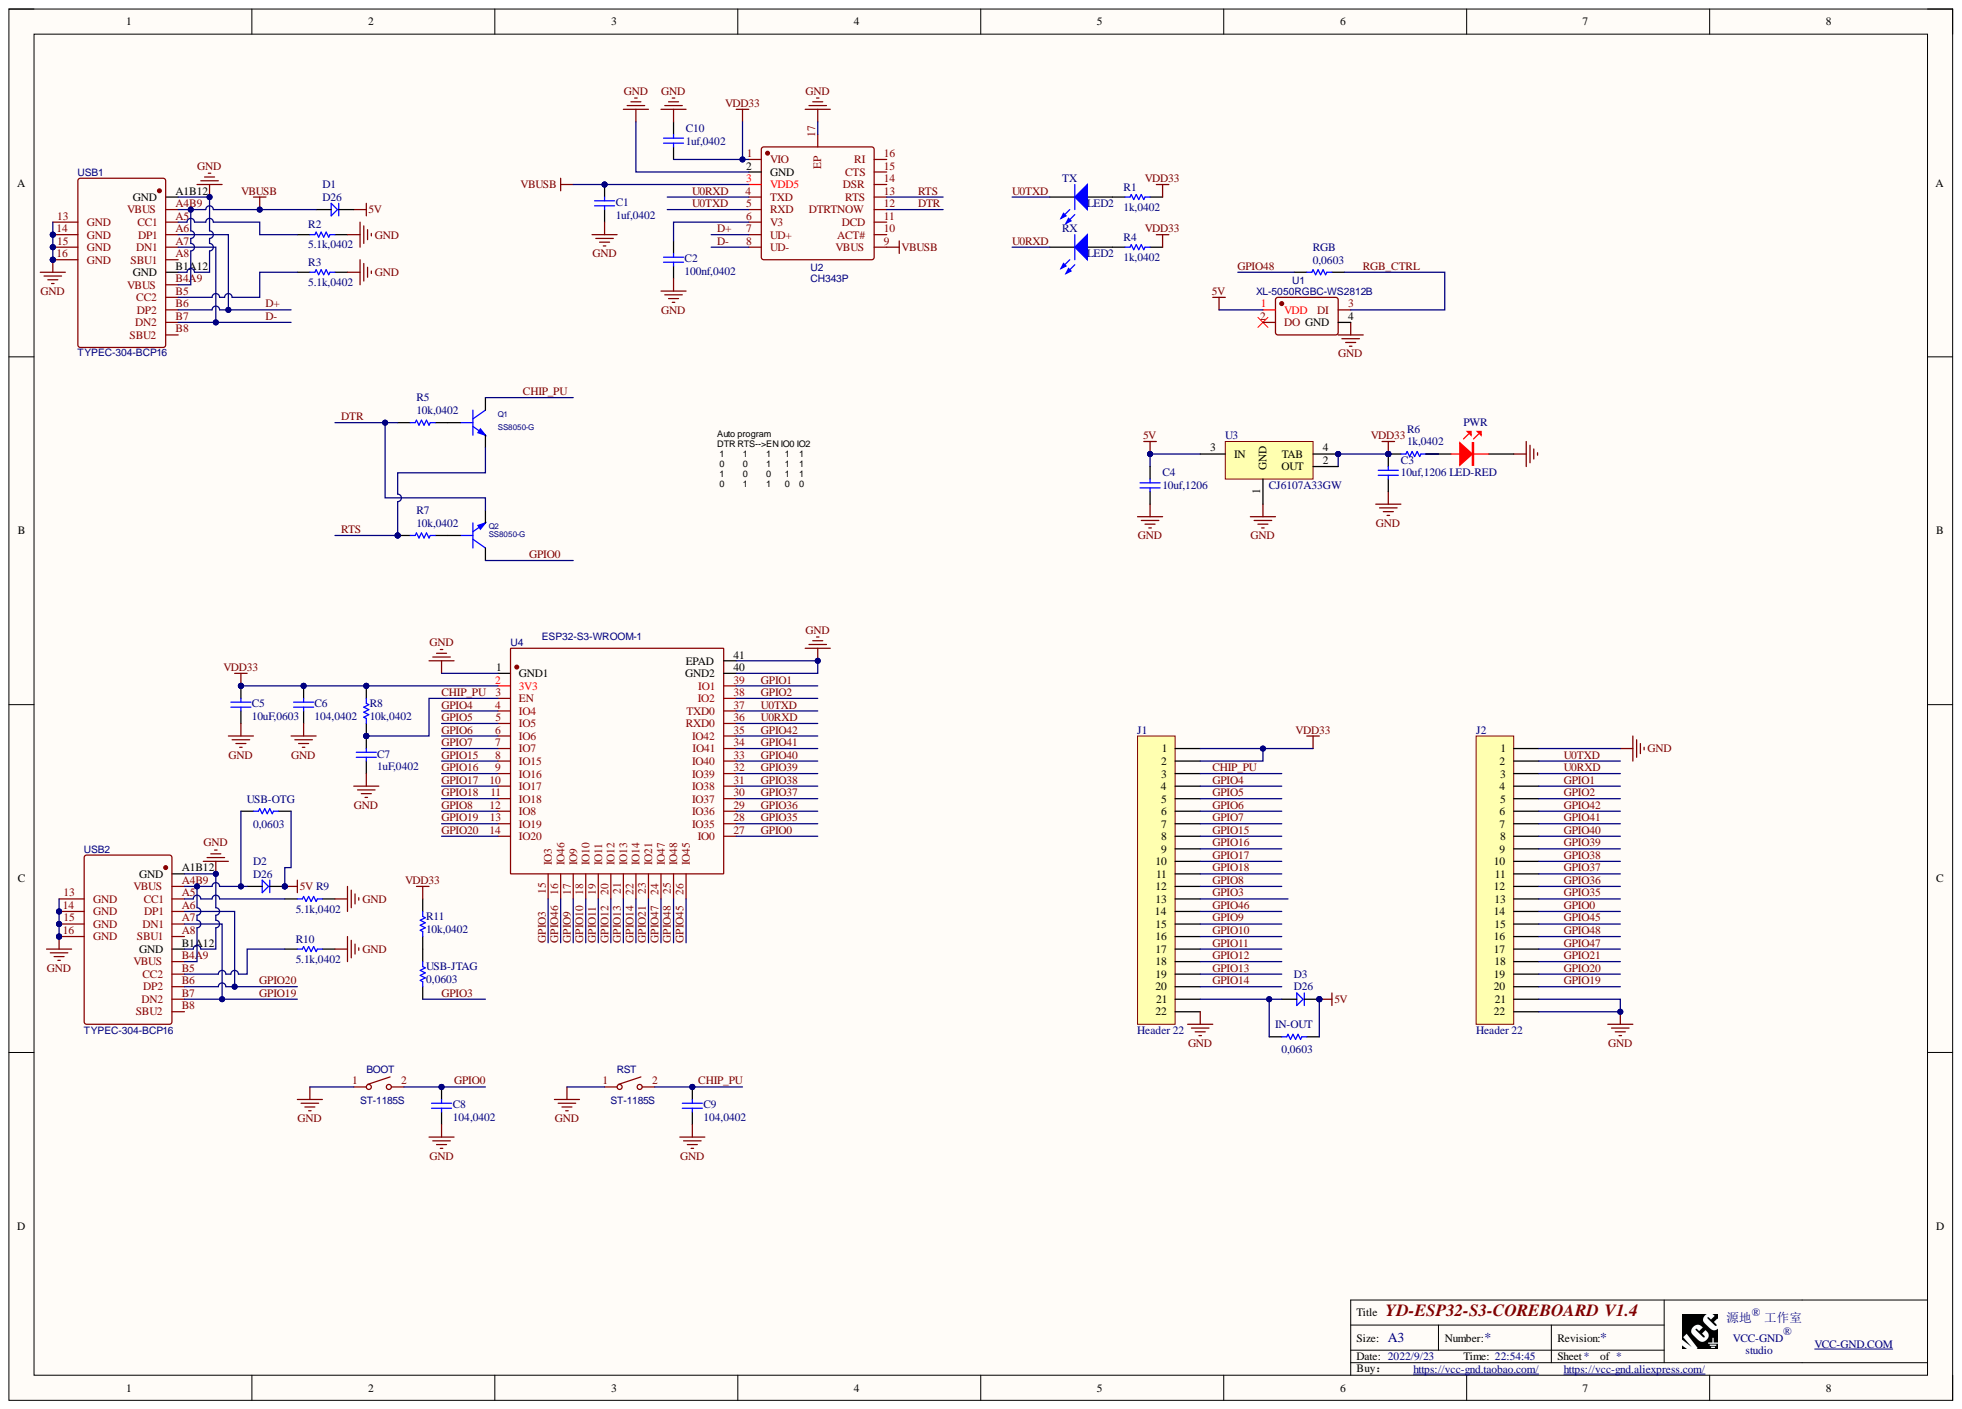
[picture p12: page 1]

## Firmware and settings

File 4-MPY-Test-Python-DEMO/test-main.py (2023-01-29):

from machine import Pin
from neopixel import NeoPixel
import time

pin = Pin(16, Pin.OUT)   
np = NeoPixel(pin, 1)   
np[0] = (10,0,0) 
np.write()              
r, g, b = np[0]
def handle_interrupt(Pin):
    np[0] = (0, 0, 0)
    np.write()
    time.sleep_ms(150)
    
    np[0] = (0, 0, 10)
    np.write()
    time.sleep_ms(150)
    
    np[0] = (0, 0, 10)
    np.write()
    time.sleep_ms(150)
    
    np[0] = (0, 0, 0)
    np.write()
    time.sleep_ms(150)
    
    np[0] = (0, 10, 0)
    np.write()
    time.sleep_ms(150)
    
    print("test-usr key")
p0 = Pin(0)
p0.init(p0.IN, p0.PULL_UP)       
p0.irq(trigger=p0.IRQ_FALLING, handler=handle_interrupt)
